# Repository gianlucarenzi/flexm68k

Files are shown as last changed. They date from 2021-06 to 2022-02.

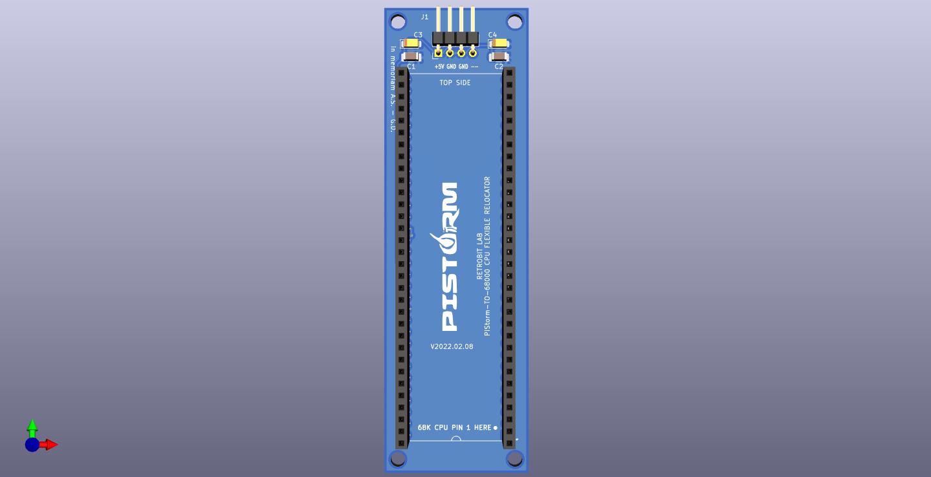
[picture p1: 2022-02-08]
flexPiStorm/images/flexPiStorm-f.png

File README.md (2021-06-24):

# flexm68k

This is a Proof Of Concept to relocate anywhere in the motherboard of an Amiga500 the CPU.
It consists of two PCB Adapter for Original Primary CPU Socket Adapter + a 64pin FFC/FPC cable and a Secondary CPU Socket Adapter with the add of power supply (as seen in the Molex Floppy Header Power Cable)

Will it work?? ;-P

Gianluca

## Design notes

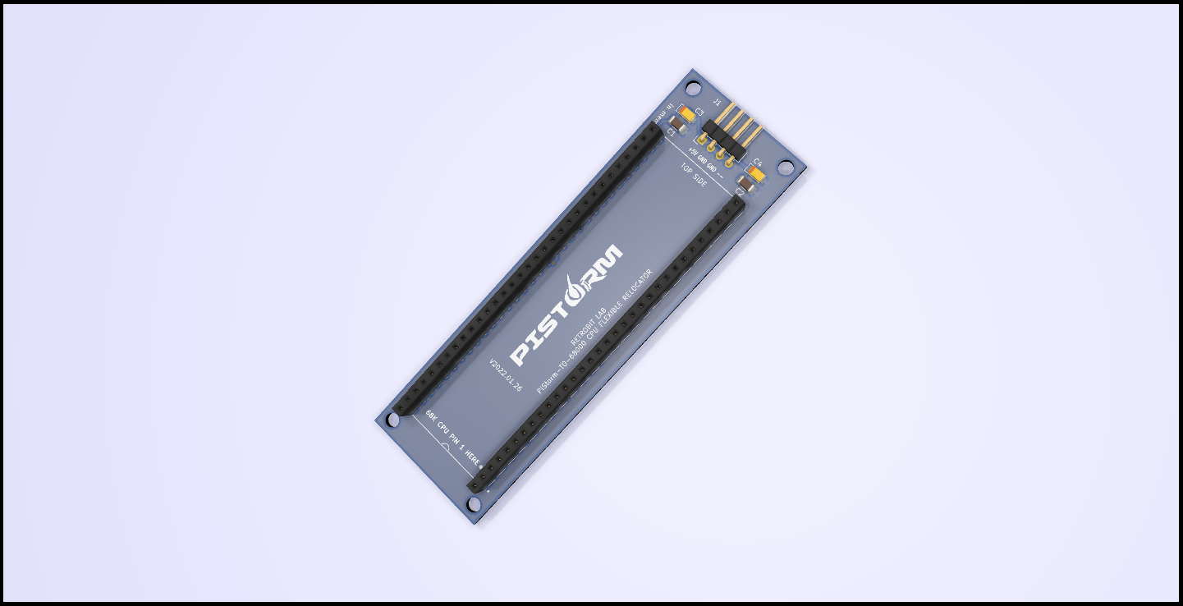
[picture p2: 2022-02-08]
flexPiStorm/images/flexPiStorm.png

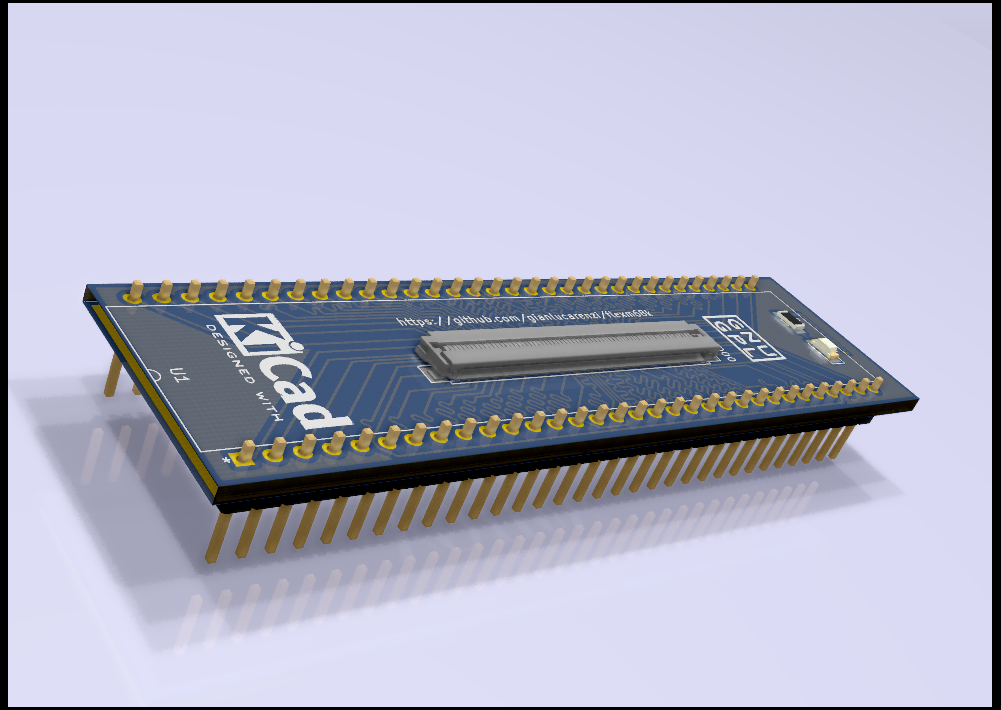
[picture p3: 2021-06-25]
flexm68k/images/flexm68k.png

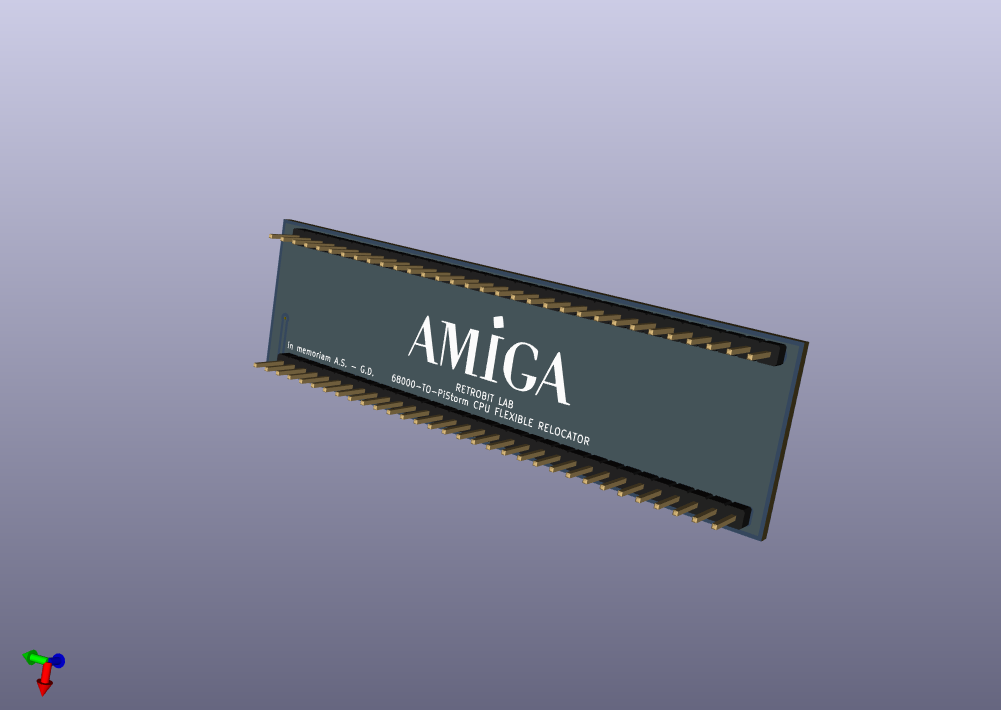
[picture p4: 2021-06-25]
flexm68k/images/flexm68k-b.png

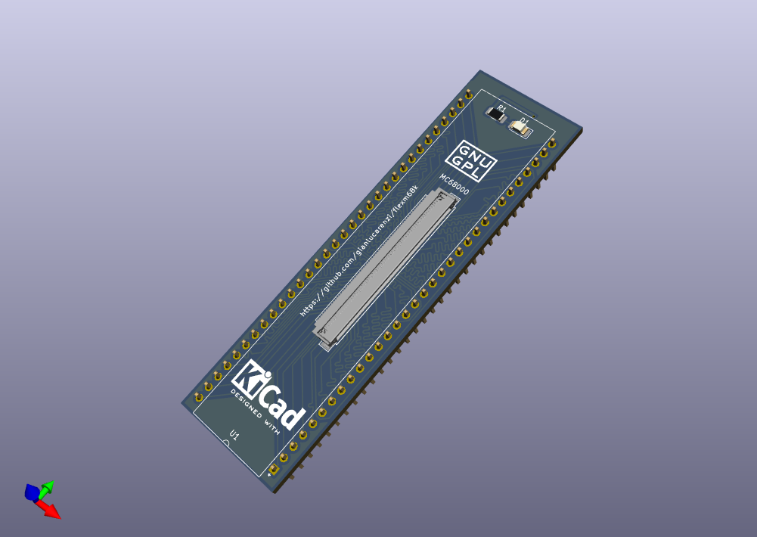
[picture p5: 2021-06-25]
flexm68k/images/flexm68k-f.png

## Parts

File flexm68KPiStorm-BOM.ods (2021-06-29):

 | 5 PCB
Id | Designator | Package | Quantity | Designation
1 | J1 | PinHeader_1x04_P2.54mm_Horizontal | 5 | Conn_01x04 | EUREK
2 | J2,J1 | FPC_64 | 10 | FPC-FFC-64 | FARNELL | https://it.farnell.com/hirose-hrs/fh52e-64s-0-5sh-99/conn-fpc-ffc-presa-64pos-0-5mm/dp/2725031
3 | D1,D1 | LED_1206_3216Metric_Pad1.42x1.75mm_HandSolder | 10 | LED 1206 | EUREK
4 | R1,R1 | R_1206_3216Metric_Pad1.30x1.75mm_HandSolder | 10 | 1K 1206 | EUREK
5 | C1,C2 | C_1206_3216Metric_Pad1.33x1.80mm_HandSolder | 10 | 100nF CER 1206 | EUREK
6 | C3,C4 | CP_EIA-3216-12_Kemet-S_Pad1.58x1.35mm_HandSolder | 10 | 10uF TANT 1206 | EUREK
7 | U1-M | 32PIN MALE STRIPS 2.54mm | 10 | 32PIN HEADER MALE | EUREK
8 | U1-F | 32PIN FEMALE HEADER 2.54mm | 10 | 32PIN FEMALE HEADER | EUREK
9 | FFC64 | 64PIN FFC/FPC FLAT CABLE 0.50 SAME SIDE 20CM | 10 | FFC64 | ALIEXPRESS | https://www.aliexpress.com/snapshot/0.html?productId=1005001375682581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

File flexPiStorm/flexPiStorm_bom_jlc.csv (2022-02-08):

Comment | Designator | Footprint | LCSC Part #
MC68000 | U1
Conn_01x04 | J1
PiStorm LOGO Design | L3
100nF | C1 C2
10uF | C3 C4
FPC-FFC-64 | J2
LED_Small | D1
1K | R1
GNU GPL LOGO | L1
KiCad LOGO Design | L2

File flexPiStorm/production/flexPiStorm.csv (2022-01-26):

Id | Designator | Package | Quantity | Designation | Supplier and ref
1 | J2 | FPC_64 | 1 | FPC-FFC-64
2 | U1 | MC68000-SOCKET-RELOCATOR_FEMALE | 1 | MC68000
3 | J1 | PinHeader_1x04_P2.54mm_Horizontal | 1 | Conn_01x04
4 | H1,H2,H3,H4 | MountingHole_3.2mm_M3 | 4 | MountingHole
5 | D1 | LED_1206_3216Metric_Pad1.42x1.75mm_HandSolder | 1 | LED_Small
6 | R1 | R_1206_3216Metric_Pad1.30x1.75mm_HandSolder | 1 | 1K
7 | L1 | Symbol_GNU-GPL_SilkScreen_Small | 1 | GNU GPL LOGO
8 | L2 | KiCad-Logo2_6mm_SilkScreen | 1 | KiCad LOGO Design
9 | L3 | PiStorm_32x6-NEG | 1 | PiStorm LOGO Design
10 | C1,C2 | C_1206_3216Metric_Pad1.33x1.80mm_HandSolder | 2 | 100nF
11 | C3,C4 | CP_EIA-3216-12_Kemet-S_Pad1.58x1.35mm_HandSolder | 2 | 10uF

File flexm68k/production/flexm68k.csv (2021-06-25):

Id | Designator | Package | Quantity | Designation | Supplier and ref
1 | G*** | amigaLogo_BW_31x12mm | 1 | LOGO
2 | GNULOGO | Symbol_GNU-GPL_SilkScreen_Small | 1 | Symbol_GNU-GPL_CopperTop_Small
3 | KICADLOGO | KiCad-Logo2_6mm_SilkScreen | 1 | KiCad-Logo2_6mm_SilkScreen
4 | J1 | FPC_64 | 1 | FPC-FFC-64
5 | D1 | LED_1206_3216Metric_Pad1.42x1.75mm_HandSolder | 1 | LED_Small
6 | R1 | R_1206_3216Metric_Pad1.30x1.75mm_HandSolder | 1 | 1K
7 | U1 | MC68000_REPLACEMENT | 1 | MC68000

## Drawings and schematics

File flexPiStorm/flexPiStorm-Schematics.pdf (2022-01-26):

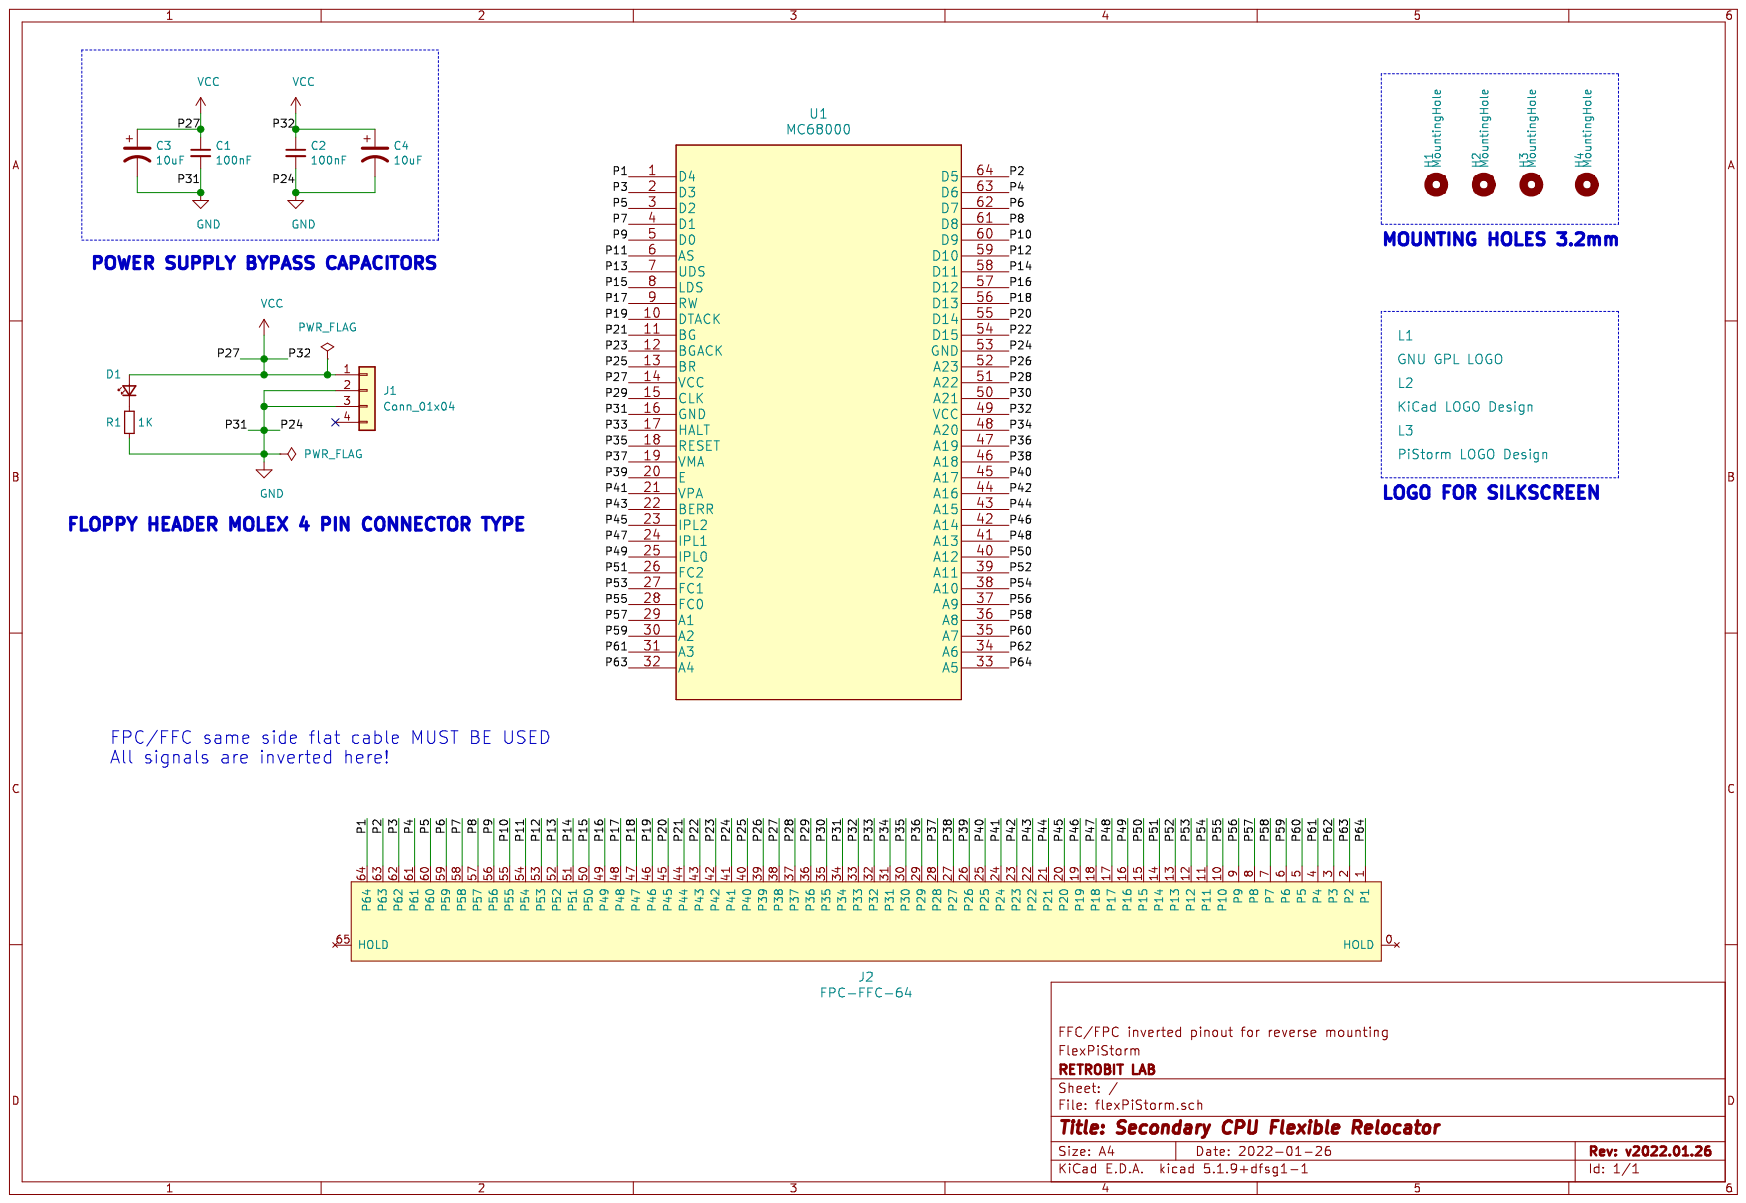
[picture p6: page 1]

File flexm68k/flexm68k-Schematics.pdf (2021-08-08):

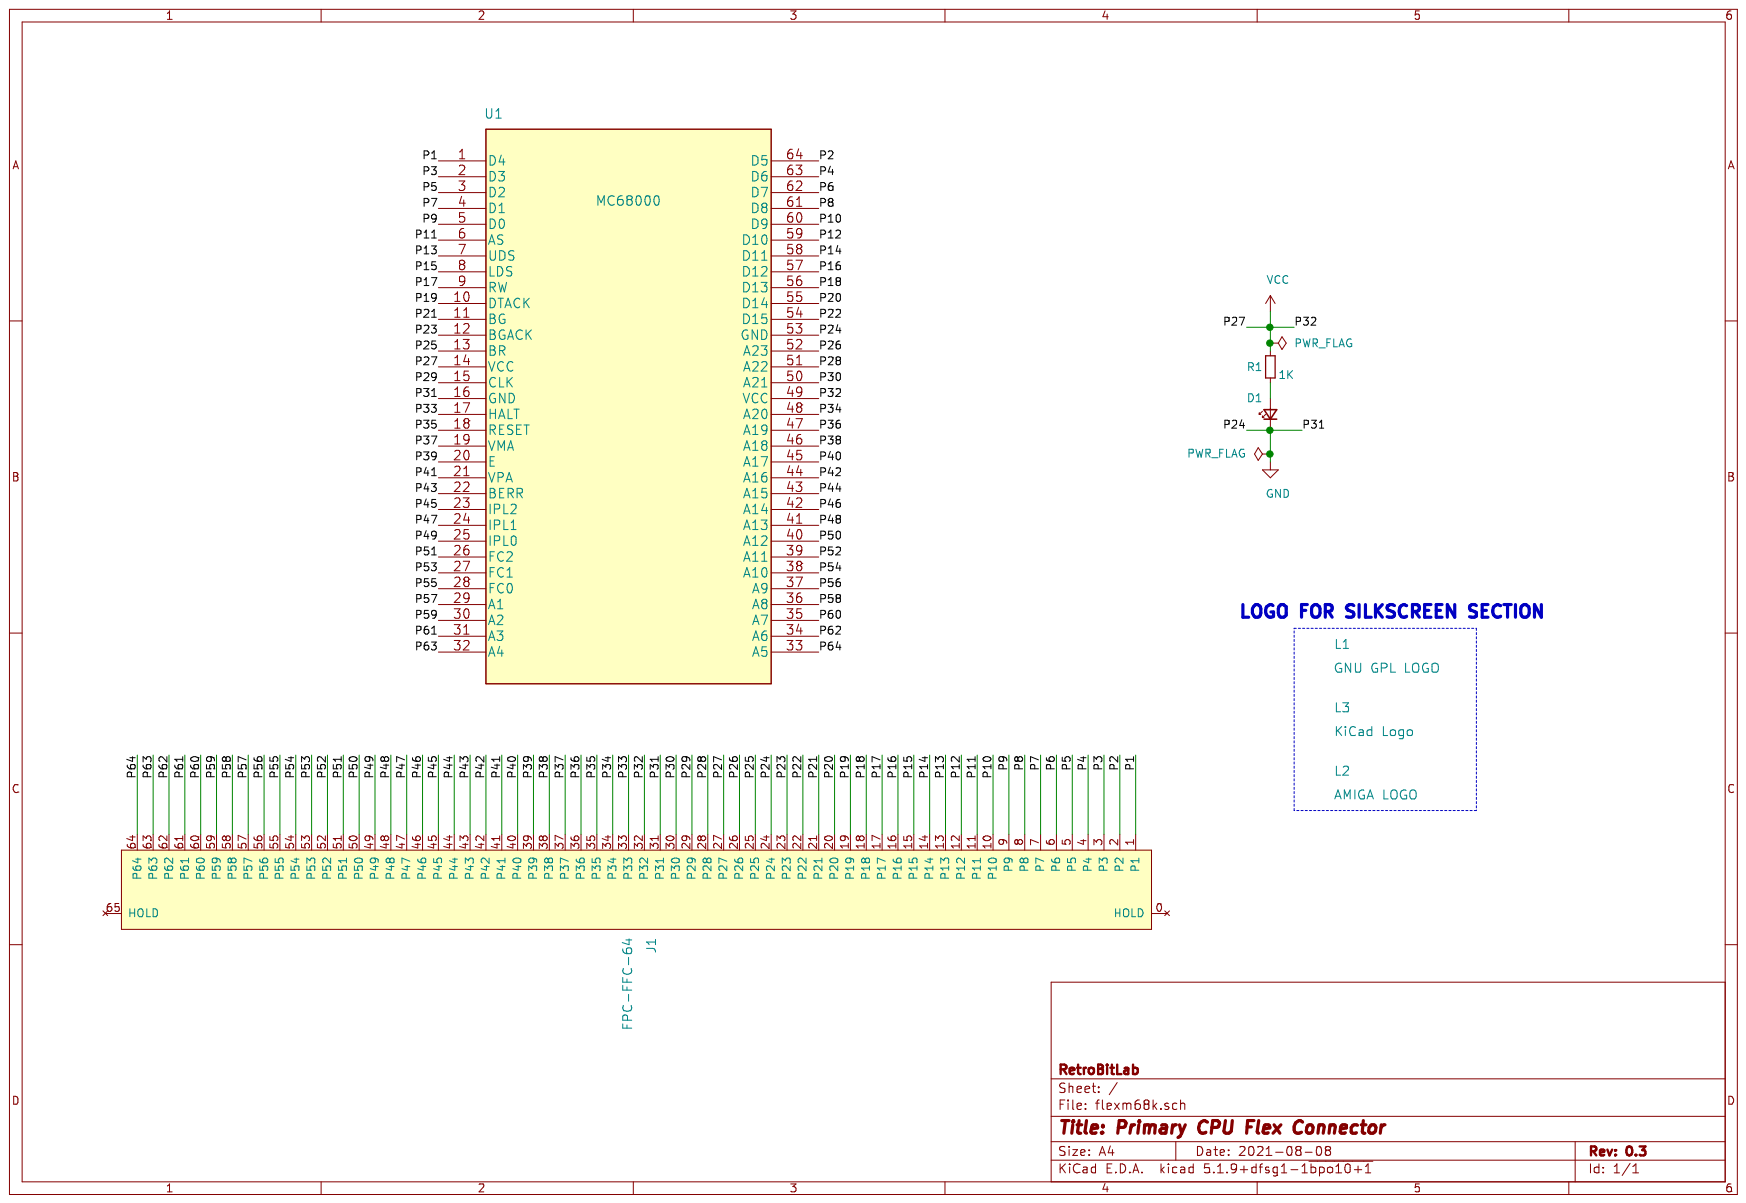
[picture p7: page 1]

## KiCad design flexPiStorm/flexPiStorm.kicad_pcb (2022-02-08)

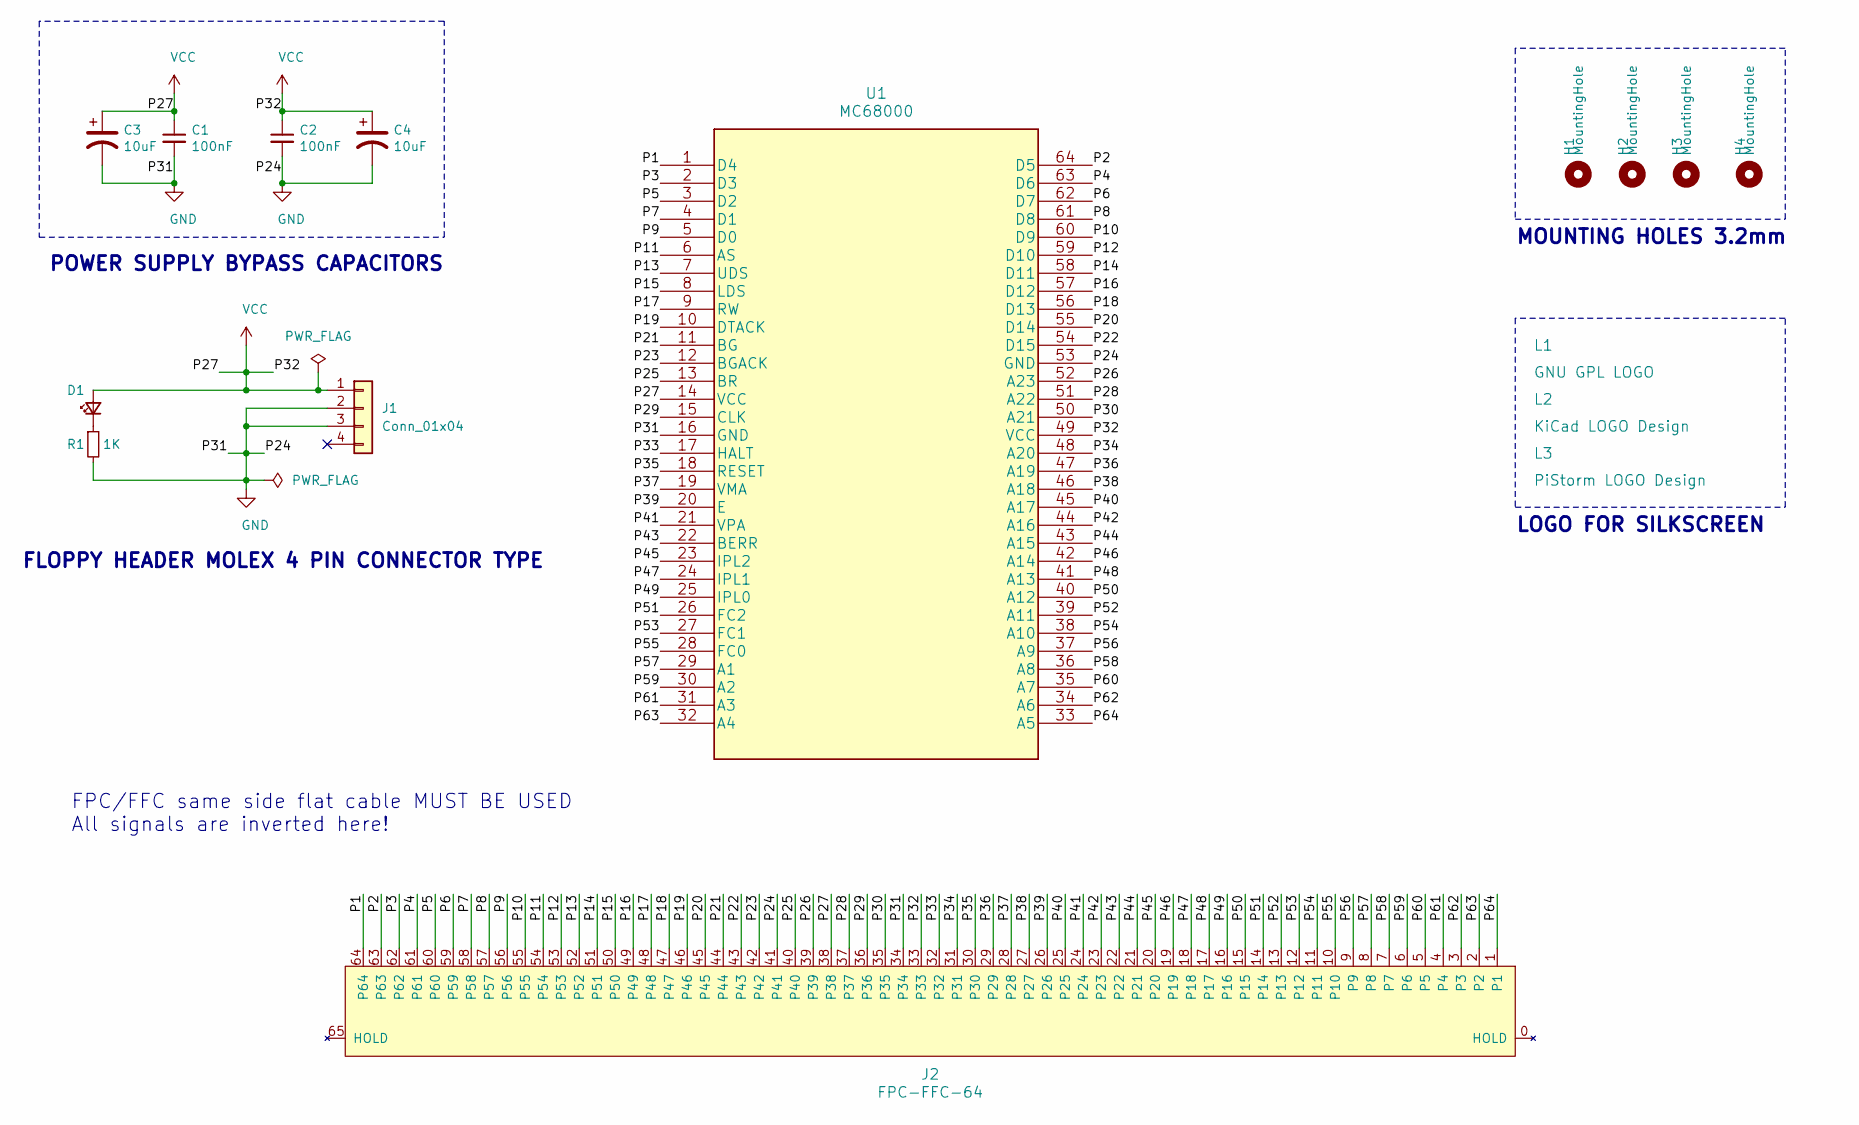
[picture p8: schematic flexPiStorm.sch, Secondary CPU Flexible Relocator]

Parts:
C1, C2: 100nF; C_1206_3216Metric_Pad1.33x1.80mm_HandSolder
C3, C4: 10uF; CP_EIA-3216-12_Kemet-S_Pad1.58x1.35mm_HandSolder
D1: LED_Small; LED_1206_3216Metric_Pad1.42x1.75mm_HandSolder
H1, H2, H3, H4: MountingHole; MountingHole_3.2mm_M3
J1: Conn_01x04; PinHeader_1x04_P2.54mm_Horizontal
J2: FPC-FFC-64; FPC_64
L1: GNU GPL LOGO; Symbol_GNU-GPL_SilkScreen_Small
L2: KiCad LOGO Design; KiCad-Logo2_6mm_SilkScreen
L3: PiStorm LOGO Design; PiStorm_32x6-NEG
R1: 1K; R_1206_3216Metric_Pad1.30x1.75mm_HandSolder
U1: MC68000; MC68000-SOCKET-RELOCATOR_FEMALE

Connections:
/P1: J2.64, U1.1 (D4)
/P2: J2.63, U1.64 (D5)
/P3: J2.62, U1.2 (D3)
/P4: J2.61, U1.63 (D6)
/P5: J2.60, U1.3 (D2)
/P6: J2.59, U1.62 (D7)
/P7: J2.58, U1.4 (D1)
/P8: J2.57, U1.61 (D8)
/P9: J2.56, U1.5 (D0)
/P10: J2.55, U1.60 (D9)
/P11: J2.54, U1.6 (AS)
/P12: J2.53, U1.59 (D10)
/P13: J2.52, U1.7 (UDS)
/P14: J2.51, U1.58 (D11)
/P15: J2.50, U1.8 (LDS)
/P16: J2.49, U1.57 (D12)
/P17: J2.48, U1.9 (RW)
/P18: J2.47, U1.56 (D13)
/P19: J2.46, U1.10 (DTACK)
/P20: J2.45, U1.55 (D14)
/P21: J2.44, U1.11 (BG)
/P22: J2.43, U1.54 (D15)
/P23: J2.42, U1.12 (BGACK)
/P25: J2.40, U1.13 (BR)
/P26: J2.39, U1.52 (A23)
/P28: J2.37, U1.51 (A22)
/P29: J2.36, U1.15 (CLK)
/P30: J2.35, U1.50 (A21)
/P33: J2.32, U1.17 (HALT)
/P34: J2.31, U1.48 (A20)
/P35: J2.30, U1.18 (RESET)
/P36: J2.29, U1.47 (A19)
/P37: J2.28, U1.19 (VMA)
/P38: J2.27, U1.46 (A18)
/P39: J2.26, U1.20 (E)
/P40: J2.25, U1.45 (A17)
/P41: J2.24, U1.21 (VPA)
/P42: J2.23, U1.44 (A16)
/P43: J2.22, U1.22 (BERR)
/P44: J2.21, U1.43 (A15)
/P45: J2.20, U1.23 (IPL2)
/P46: J2.19, U1.42 (A14)
/P47: J2.18, U1.24 (IPL1)
/P48: J2.17, U1.41 (A13)
/P49: J2.16, U1.25 (IPL0)
/P50: J2.15, U1.40 (A12)
/P51: J2.14, U1.26 (FC2)
/P52: J2.13, U1.39 (A11)
/P53: J2.12, U1.27 (FC1)
/P54: J2.11, U1.38 (A10)
/P55: J2.10, U1.28 (FC0)
/P56: J2.9, U1.37 (A9)
/P57: J2.8, U1.29 (A1)
/P58: J2.7, U1.36 (A8)
/P59: J2.6, U1.30 (A2)
/P60: J2.5, U1.35 (A7)
/P61: J2.4, U1.31 (A3)
/P62: J2.3, U1.34 (A6)
/P63: J2.2, U1.32 (A4)
/P64: J2.1, U1.33 (A5)
GND: C1.2, C2.2, C3.2, C4.2, J1.2, J1.3, J2.34, J2.41, R1.2, U1.16 (GND), U1.53 (GND)
unnamed: D1.1 (K), R1.1
VCC: C1.1, C2.1, C3.1, C4.1, D1.2 (A), J1.1, J2.33, J2.38, U1.14 (VCC), U1.49 (VCC)

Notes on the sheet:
MOUNTING HOLES 3.2mm
LOGO FOR SILKSCREEN
FLOPPY HEADER MOLEX 4 PIN CONNECTOR TYPE
POWER SUPPLY BYPASS CAPACITORS
FPC/FFC same side flat cable MUST BE USED All signals are inverted here!

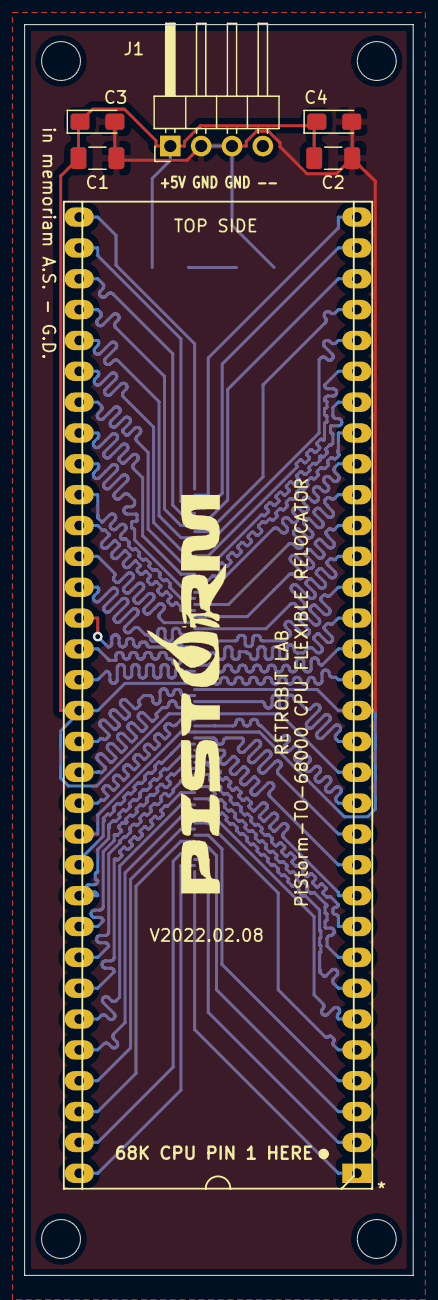
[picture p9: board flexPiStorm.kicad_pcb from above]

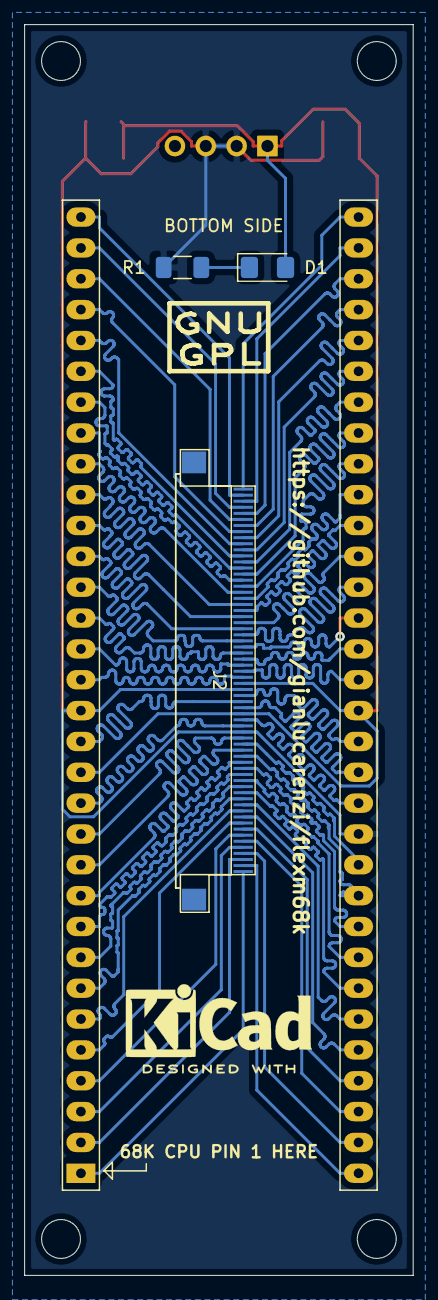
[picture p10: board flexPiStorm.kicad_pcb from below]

Board: 2 copper layers, 32.0 x 103.0 mm, 16 parts (5 on the bottom side), 63 nets.

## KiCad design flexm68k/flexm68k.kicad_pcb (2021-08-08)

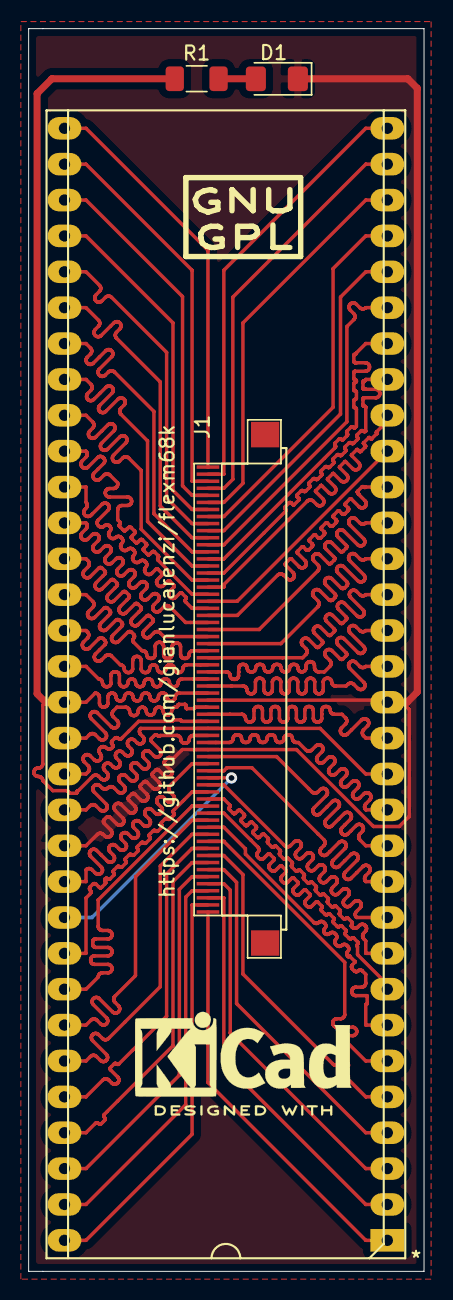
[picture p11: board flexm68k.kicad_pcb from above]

Board: 2 copper layers, 28.0 x 88.0 mm, 7 parts (1 on the bottom side), 63 nets.

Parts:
D1: LED_Small; LED_1206_3216Metric_Pad1.42x1.75mm_HandSolder
J1: FPC-FFC-64; FPC_64
L1: GNU GPL LOGO; Symbol_GNU-GPL_SilkScreen_Small
L2: AMIGA LOGO; amigaLogo_BW_31x12mm
L3: KiCad Logo; KiCad-Logo2_6mm_SilkScreen
R1: 1K; R_1206_3216Metric_Pad1.30x1.75mm_HandSolder
U1: MC68000; MC68000-RELOCATOR-MALE

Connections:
/P1: J1.1, U1.1
/P2: J1.2, U1.64
/P3: J1.3, U1.2
/P4: J1.4, U1.63
/P5: J1.5, U1.3
/P6: J1.6, U1.62
/P7: J1.7, U1.4
/P8: J1.8, U1.61
/P9: J1.9, U1.5
/P10: J1.10, U1.60
/P11: J1.11, U1.6
/P12: J1.12, U1.59
/P13: J1.13, U1.7
/P14: J1.14, U1.58
/P15: J1.15, U1.8
/P16: J1.16, U1.57
/P17: J1.17, U1.9
/P18: J1.18, U1.56
/P19: J1.19, U1.10
/P20: J1.20, U1.55
/P21: J1.21, U1.11
/P22: J1.22, U1.54
/P23: J1.23, U1.12
/P25: J1.25, U1.13
/P26: J1.26, U1.52
/P28: J1.28, U1.51
/P29: J1.29, U1.15
/P30: J1.30, U1.50
/P33: J1.33, U1.17
/P34: J1.34, U1.48
/P35: J1.35, U1.18
/P36: J1.36, U1.47
/P37: J1.37, U1.19
/P38: J1.38, U1.46
/P39: J1.39, U1.20
/P40: J1.40, U1.45
/P41: J1.41, U1.21
/P42: J1.42, U1.44
/P43: J1.43, U1.22
/P44: J1.44, U1.43
/P45: J1.45, U1.23
/P46: J1.46, U1.42
/P47: J1.47, U1.24
/P48: J1.48, U1.41
/P49: J1.49, U1.25
/P50: J1.50, U1.40
/P51: J1.51, U1.26
/P52: J1.52, U1.39
/P53: J1.53, U1.27
/P54: J1.54, U1.38
/P55: J1.55, U1.28
/P56: J1.56, U1.37
/P57: J1.57, U1.29
/P58: J1.58, U1.36
/P59: J1.59, U1.30
/P60: J1.60, U1.35
/P61: J1.61, U1.31
/P62: J1.62, U1.34
/P63: J1.63, U1.32
/P64: J1.64, U1.33
GND: D1.1, J1.24, J1.31, U1.16, U1.53
unnamed: D1.2, R1.2
VCC: J1.27, J1.32, R1.1, U1.14, U1.49

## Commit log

2021-06-25 First import
    [flexm68k-B_Cu.gbl, flexm68k-B_Mask.gbs, flexm68k-B_Paste.gbp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]
2021-06-25 LED and RESISTOR added
    [flexm68k-B_Cu.gbl, flexm68k-B_Mask.gbs, flexm68k-B_Paste.gbp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]
2021-06-25 New flexPiStorm
    [flexPiStorm-B_Cu.gbl, flexPiStorm-B_Mask.gbs, flexPiStorm-B_Paste.gbp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]
2021-06-27 Added LOGOs in the schematics, so the PCB will have them already. Run DRC for errors. Report only three (3) overlap for silkscreen and filled zones. No problem at all.
    [flexm68k.kicad_pcb, flexm68k.sch]
2021-06-28 Added bypass capacitors 10000pF Ceramics 1206 HandSolder
    [flexPiStorm-B_Cu.gbl, flexPiStorm-B_Mask.gbs, flexPiStorm-B_Paste.gbp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]
2021-06-29 Added a better filter for powersupply TANTALUM + CERAMIC (x2)
    [flexPiStorm-B_Cu.gbl, flexPiStorm-B_Mask.gbs, flexPiStorm-B_Paste.gbp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]
2021-06-29 FFC/FPC Flex Cables from AliExpress FFC/FPC Connectors 64PIN 0.5mm from Farnell Other components provided by Eurek SRL
    [flexm68KPiStorm-BOM.ods]
2021-08-08 Wrong footprint for CPU. Now should be corrected
    [flexm68k-B_Cu.gbl, flexm68k-B_Mask.gbs, flexm68k-B_Paste.gbp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]
2021-08-08 Modified for correct footprint CPU
    [flexPiStorm-B_Cu.gbl, flexPiStorm-B_Mask.gbs, flexPiStorm-B_Paste.gbp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]
2022-01-26 Inverted ffc/fpc pinout for reverse mounting. Cable must be SAME SIDE
    [flexPiStorm.dsn, flexPiStorm.kicad_pcb, flexPiStorm.sch]
2022-01-26 interactive bom
2022-02-08 Modified as requested by JLCPCB with e-mail in beginning of Feb. 2022 (Tracks too small)
    [flexPiStorm-B_Cu.gbl, flexPiStorm-B_Mask.gbs, flexPiStorm-B_Paste.gbp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]
2022-02-08 Added for future usage for JLCPCB
    [flexPiStorm_bom_bottom.csv, flexPiStorm_bom_jlc.csv, flexPiStorm_bom_top.csv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]
